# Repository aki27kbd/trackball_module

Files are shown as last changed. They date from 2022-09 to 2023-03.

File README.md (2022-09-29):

# trackball_module

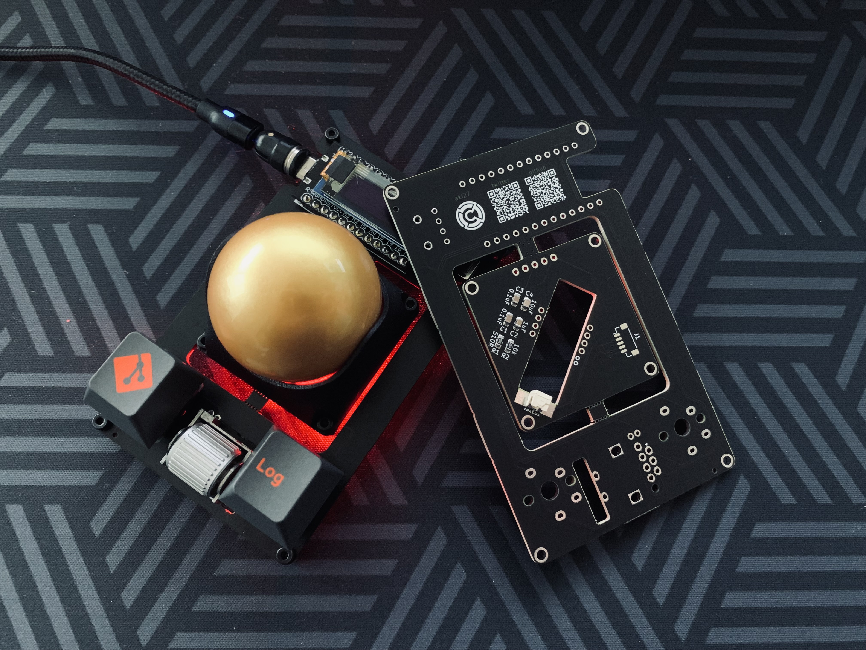
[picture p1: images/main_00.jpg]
trackball_module_main00


This is a module part for 34mm trackball with ADNS-5050 sensor. Module size is within 2u x 2u (38mm x 38mm) so that it can be easily implemented with existing DIY keyboards. Connection with other boards is via 2.54mm-pitched 5 pins or 1.0mm-pitched SH connector. The module is embedded with a Meishi (name card) sized PCB which can also work as a stand-alone mini trackball with two keys, a rotary encoder and an OLED display.

- Keyboard Maintainer: [aki27kbd](https://github.com/aki27kbd) [@aki27kbd](https://twitter.com/aki27kbd)
- Hardware Supported: meishi trackball module PCB, ProMicro
- Hardware Availability: [BOOTH](https://aki27.booth.pm)
  Go on sale in October 2022.

Build Guide [JP](doc/buildguide.md) / [EN](doc/buildguide_en.md)

## 1. Stand-alone Mini Trackball
Meishi trackball module can be used as a mini trackball running on QMK. Keycodes and rotary encoder settings are easily customized via [Remap](https://remap-keys.app/).

### BOM
|名前|数|備考|
|---|---|---|
|MicroUSB or USB-TypeCケーブル|1本||
|ProMicro|1個||
|コンスル― or ピンヘッダ（12ピン）|2本||
|キースイッチ|2個|MX互換 or Choc v1|
|キーキャップ（1U）|2個|MX互換 or Choc v1|
|ロータリーエンコーダ（EC12互換）|1個|水平タイプも可|
|ロータリーエンコーダ用ノブ|1個|最大直径16mm以下|
|OLEDモジュール|1個||
|OLED用ピンソケット|1個||
|OLED用ピンヘッダ|1個||
|リセットスイッチ|1個||
|34mmボール|1個||
|M2ねじ 6mm|4本||
|M2ナット|4個||
|アクリルボトムプレート|1枚|オプション|
|M2ねじ 4mm|8本||
|M2スペーサー 6mm|4本||

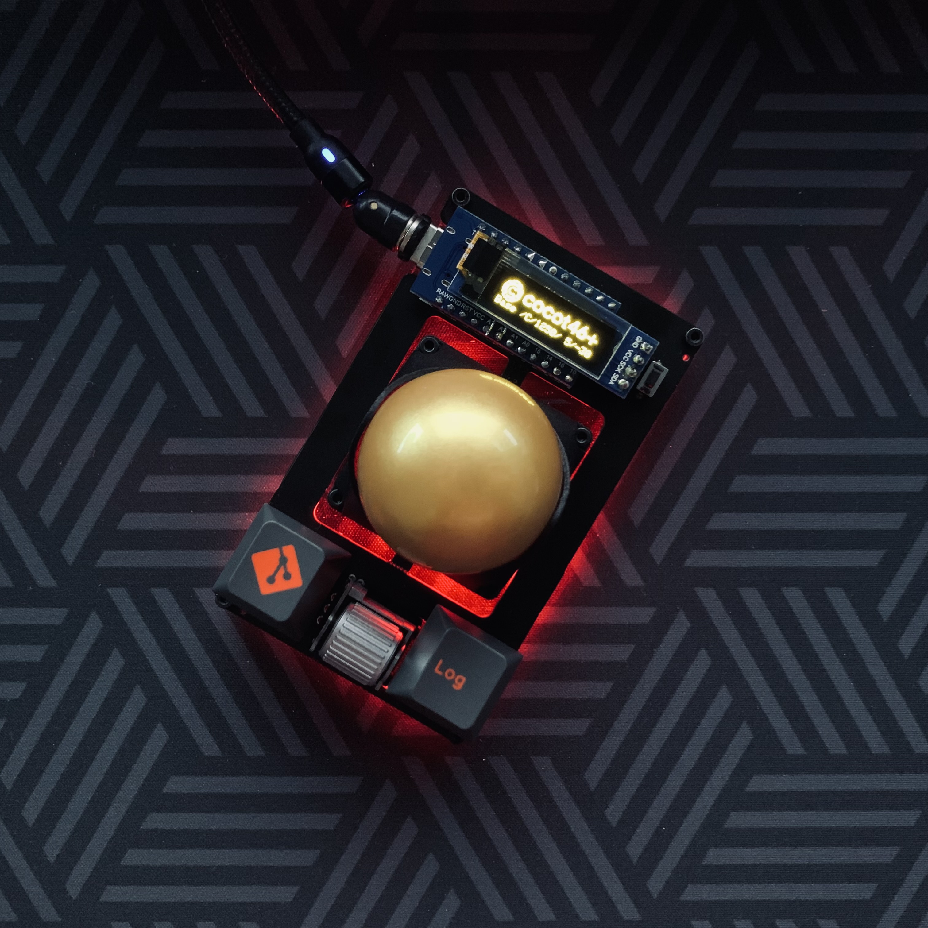
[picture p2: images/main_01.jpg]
trackball_module_main01


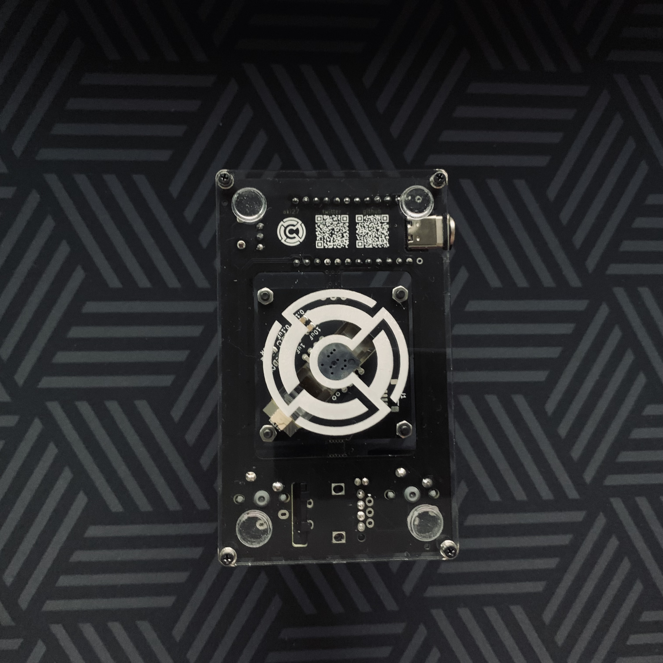
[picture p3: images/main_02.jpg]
trackball_module_main02


## 2. Trackball Module

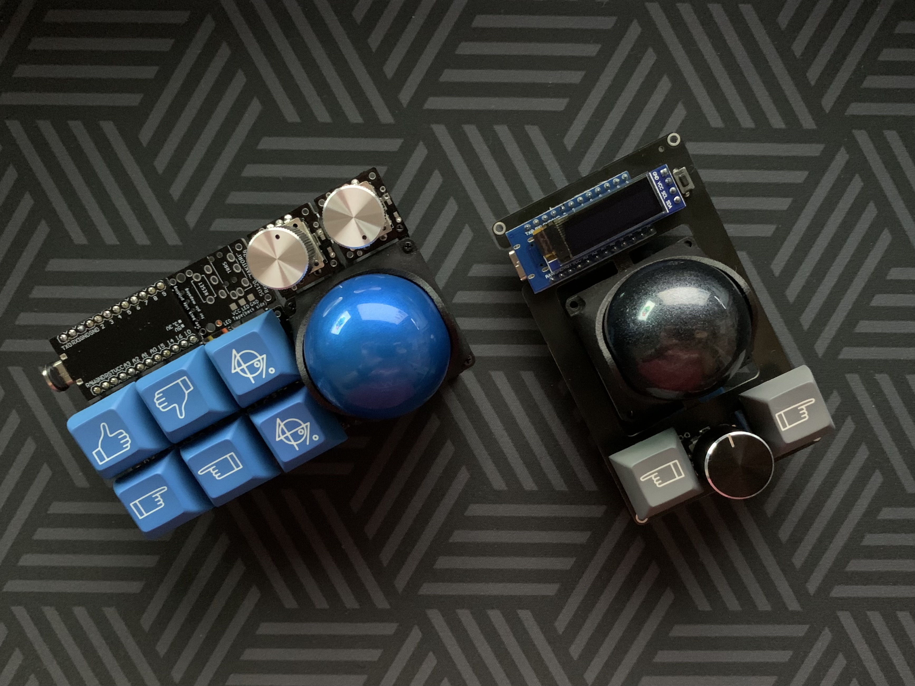
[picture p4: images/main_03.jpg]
trackball_module_main03


Square part located at the center of Meishi PCB can be cut off and used as a trackball module. There are several ways to connect this module with main boards.

1. Pin Headers & Pin Sockets  
  5 pins need to be connected. Straight and L-angle types are available.

2. Cables
  Cabling/wiring between pins of the module and the main board.

3. SH Connectors
  SH horizontal connectors are also supported for the connection with external boards.

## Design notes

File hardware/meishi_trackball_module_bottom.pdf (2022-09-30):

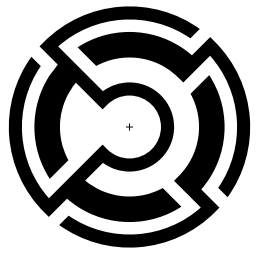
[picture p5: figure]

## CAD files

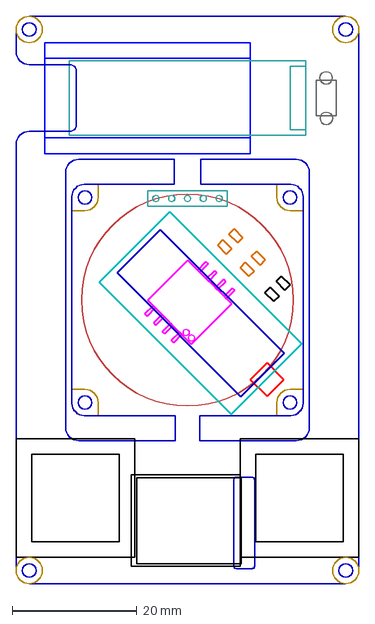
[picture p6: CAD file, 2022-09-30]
hardware/meishi_trackball_module_issue.dxf
55.0 x 91.0 mm

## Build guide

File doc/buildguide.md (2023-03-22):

# Build Guide

trackball_module_main00

trackball_module_main00

meishi trackball moduleのビルドガイドになります。
meishi trackball moduleは、名刺サイズ（55mm×91mm）の自作トラックボール検証基板です。そのまま組み立てることで、34mmトラックボールとスイッチ×2、ロータリーエンコーダ、OLEDを搭載したマウスやマクロパッドとして利用することが可能です。  
また、中央の2u×2u（38mm×38mm）のプレートは切り離すことで、そのままトラックボールモジュールとして他のキーボードに搭載可能です。詳細はこちらを参照ください。

## 部品
### キット付属品

#### ベースセット付属品

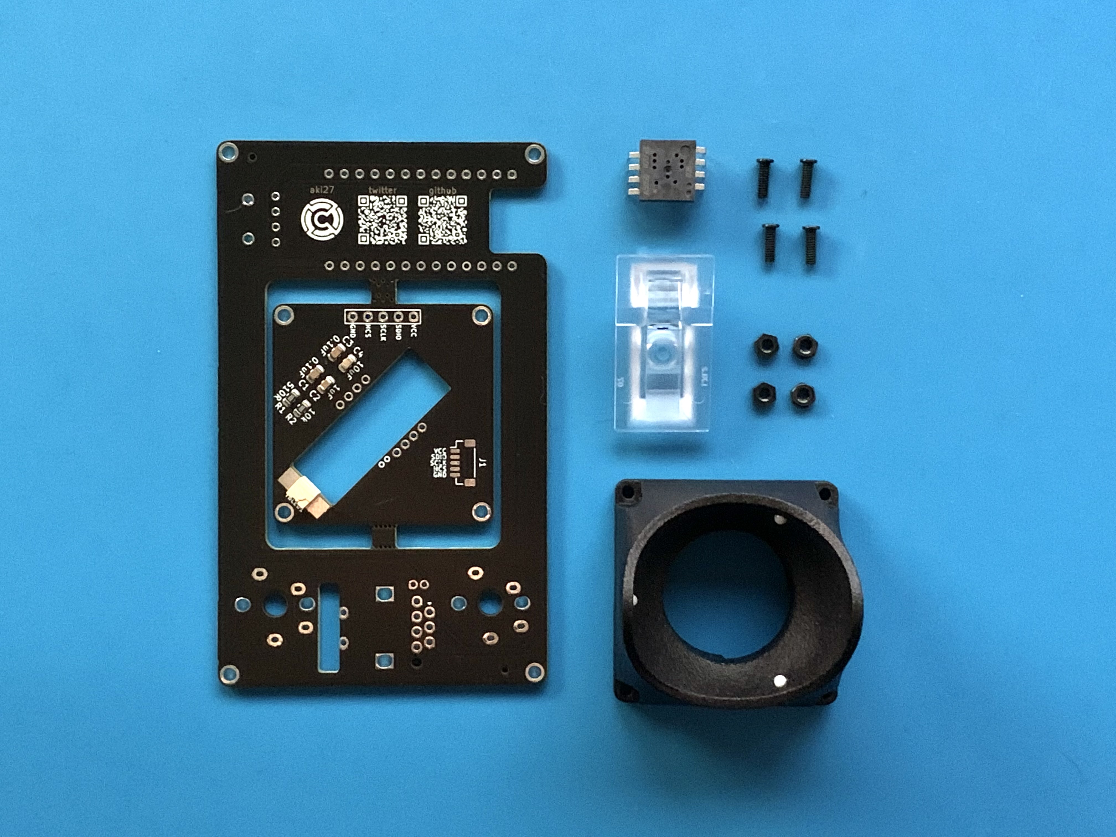
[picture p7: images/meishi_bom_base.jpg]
meishi_bom_bottom


#### アクリルボトムプレート付属品（オプション）

アクリルボトムプレートを自身で発注する際はこちらのデータを改編してお使いください。  
[アクリルボトムプレート](https://github.com/aki27kbd/trackball_module/blob/main/hardware/meishi_trackball_module_bottom.pdf)

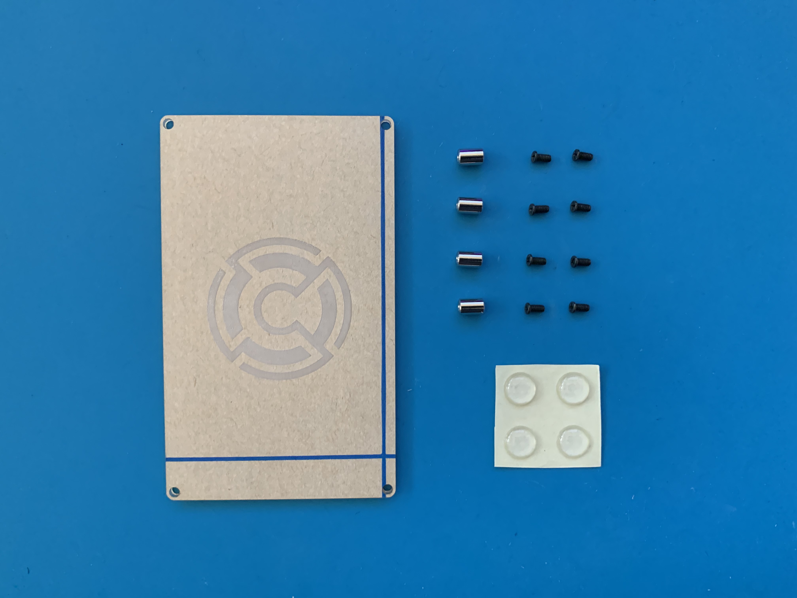
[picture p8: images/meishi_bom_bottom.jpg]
meishi_bom_bottom


|名前|数|備考|
|---|---|---|
|実装済基板|1枚||
|ProMicro|1個||
|マウスセンサー（ADNS-5050）|1個||
|センサーレンズ|1個||
|3Dプリント製ボールケース|1個||
|M2ねじ 6mm|4本||
|M2ナット|4個||
|アクリルボトムプレート|1枚|オプション|
|M2ねじ 4mm|8本|オプション|
|M2スペーサー 6mm|4本|オプション|
|ゴム脚|4個|オプション|

### キット以外に必要なもの

下記パーツは[遊舎工房](https://shop.yushakobo.jp/)、[TALP KEYBOARD](https://talpkeyboard.net/)、[Daily Craft Keyboard](https://shop.dailycraft.jp/)などで揃えることが可能です。また、18mm径ノブは[へちょあまの工房＠たねやつ支店](https://taneyats.booth.pm/items/3512697)での品揃えが豊富です。

|名前|数|備考|
|---|---|---|
|MicroUSB or USB-TypeCケーブル|1本||
|ProMicro|1個||
|コンスル― or ピンヘッダ（2.5mm×12ピン）|2本||
|キースイッチ|2個|MX互換 or Choc v1|
|キーキャップ（1U）|2個|MX互換 or Choc v1|
|ロータリーエンコーダ（EC12互換）|1個|水平タイプも可|
|ロータリーエンコーダ用ノブ|1個|最大直径18mm以下|
|OLEDモジュール|1個||
|OLED用ピンソケット|1個||
|OLED用ピンヘッダ|1個||
|リセットスイッチ|1個||
|34mmボール|1個||

各ショップの在庫状況に応じて検討ください。

## 組み立て

### 1. センサー

  基板の裏面からセンサーを固定します。写真の赤枠のように、センサーの丸印と基板の丸印の位置が揃うように気を付けてください。マスキングテープなどで固定した後、表側から8本の脚をはんだ付けしてください。

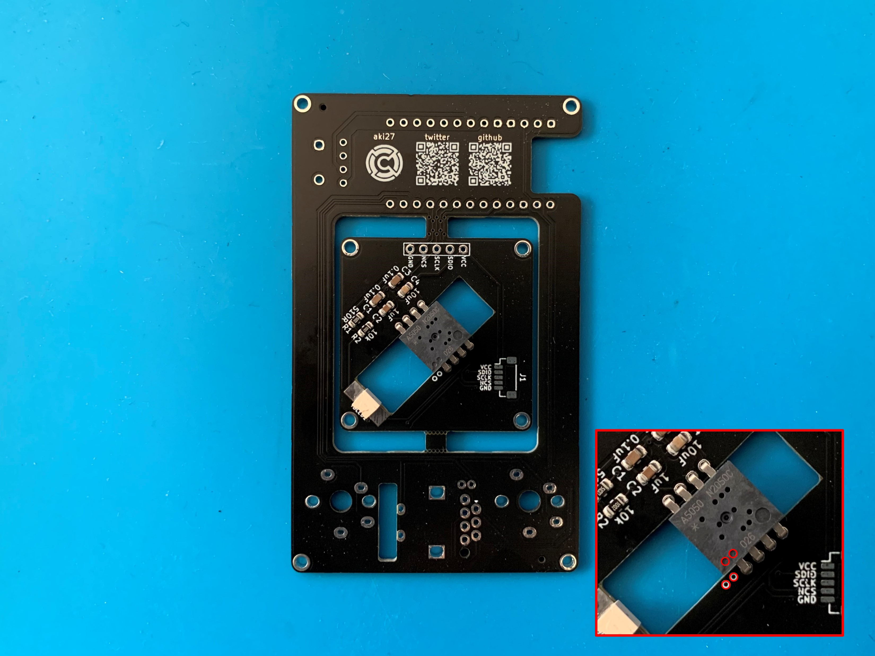
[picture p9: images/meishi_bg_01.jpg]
meishi_bg_01
  

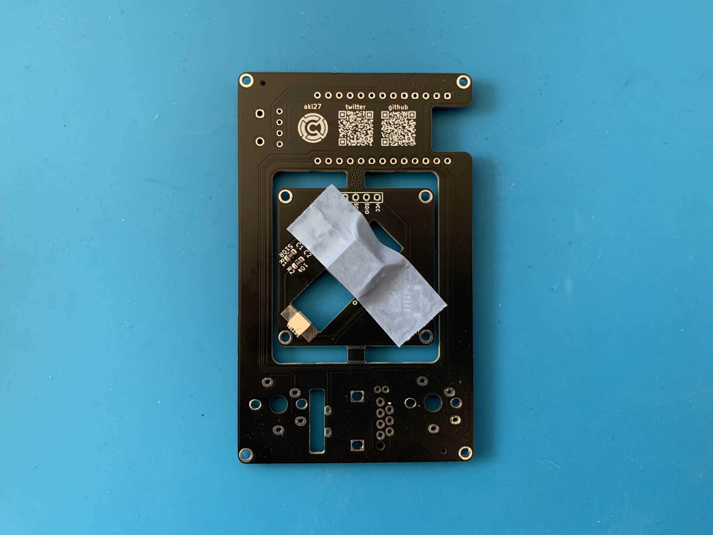
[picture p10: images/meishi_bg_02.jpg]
meishi_bg_02
  

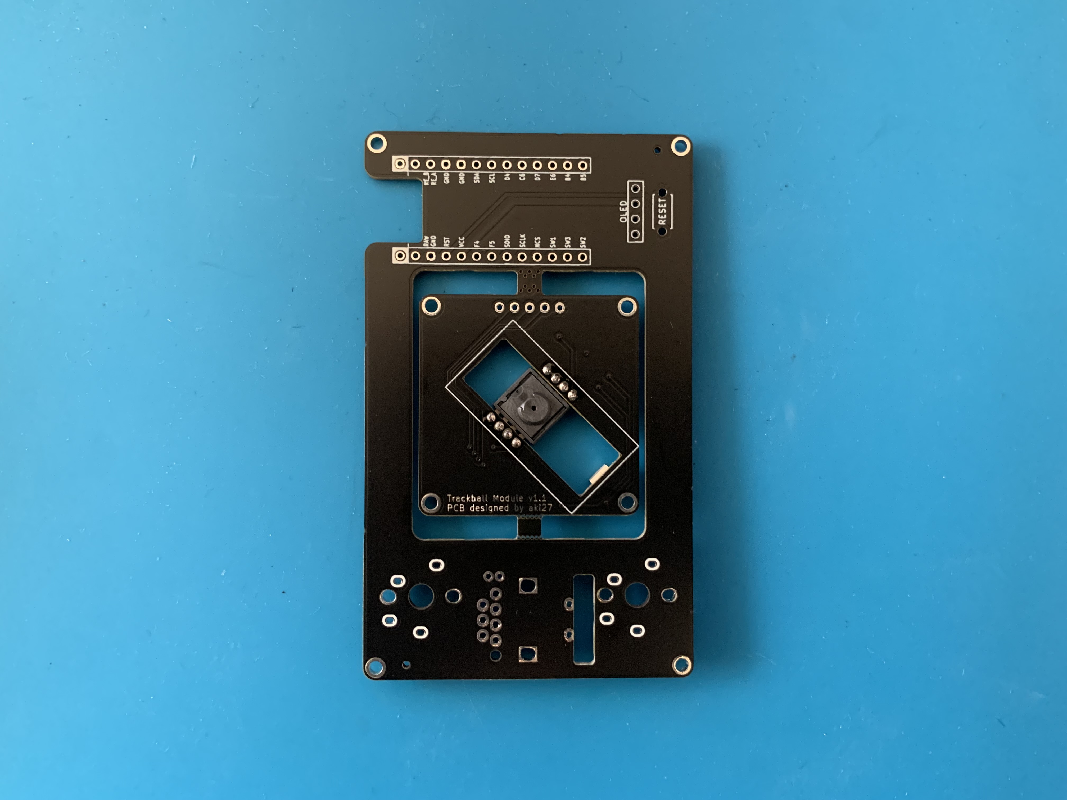
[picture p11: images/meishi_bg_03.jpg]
meishi_bg_03
  

### 2. ロータリーエンコーダ

  続いてロータリーエンコーダのはんだ付けを行います。**必ずキースイッチの前にロータリーエンコーダのはんだ付けを行ってください。**  
  水平ロータリーエンコーダの場合は下記写真のように表側から基板に固定し、裏側6本の脚をはんだ付けしてください。

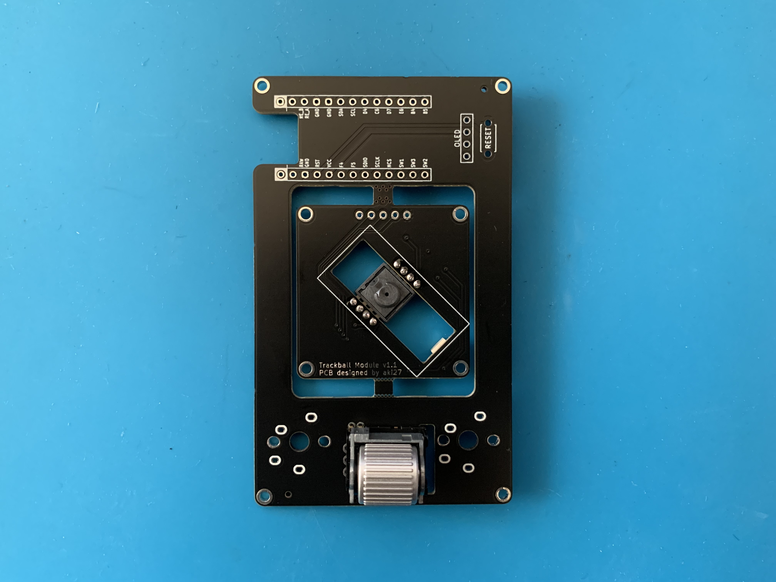
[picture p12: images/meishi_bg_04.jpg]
meishi_bg_04
  

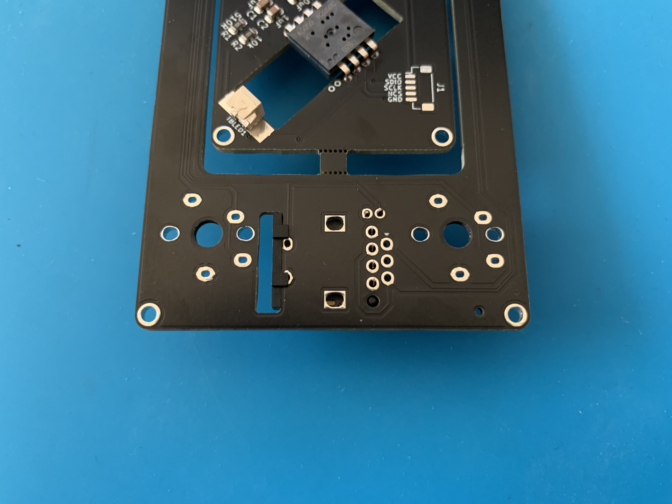
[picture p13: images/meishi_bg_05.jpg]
meishi_bg_05
  

  通常のロータリーエンコーダの場合は下記写真のように表側から基板に固定し、裏側5本の脚をはんだ付けしてください。

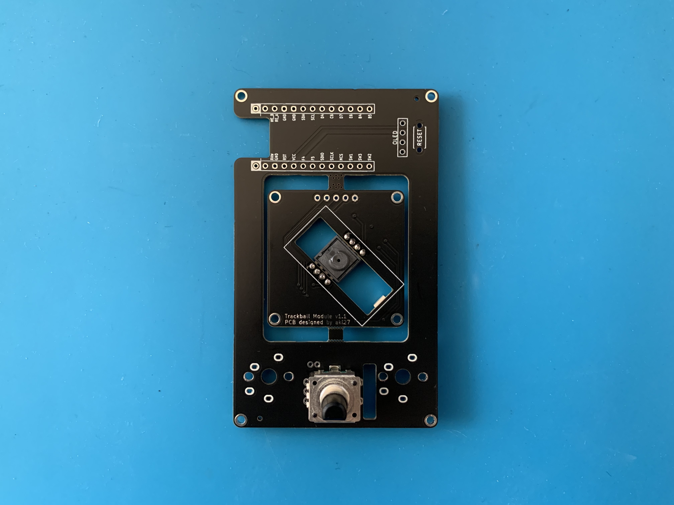
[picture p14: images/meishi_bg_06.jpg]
meishi_bg_06
  

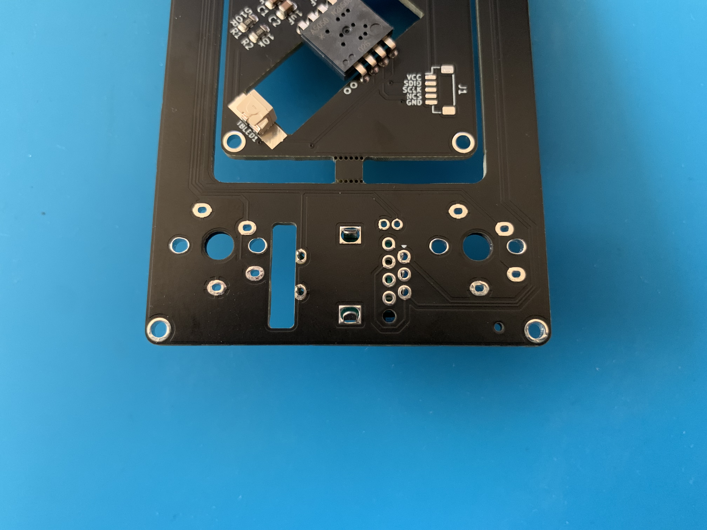
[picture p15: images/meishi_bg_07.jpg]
meishi_bg_07
  

### 3. キースイッチ

  キースイッチ2個を基板の表側から差し込み、裏側2本の脚×2個の計4か所のはんだ付けしてください。

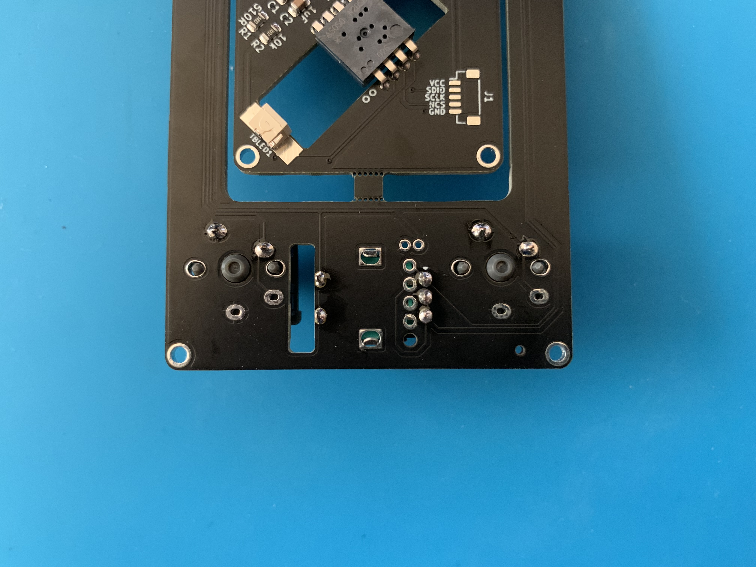
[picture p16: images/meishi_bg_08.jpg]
meishi_bg_08
  

### 4. その他パーツ（オプション）

  OLED用ピンソケットを基板表側から差し込み、マスキングテープなどで固定した後、裏側から4本の脚をはんだ付けしてください。

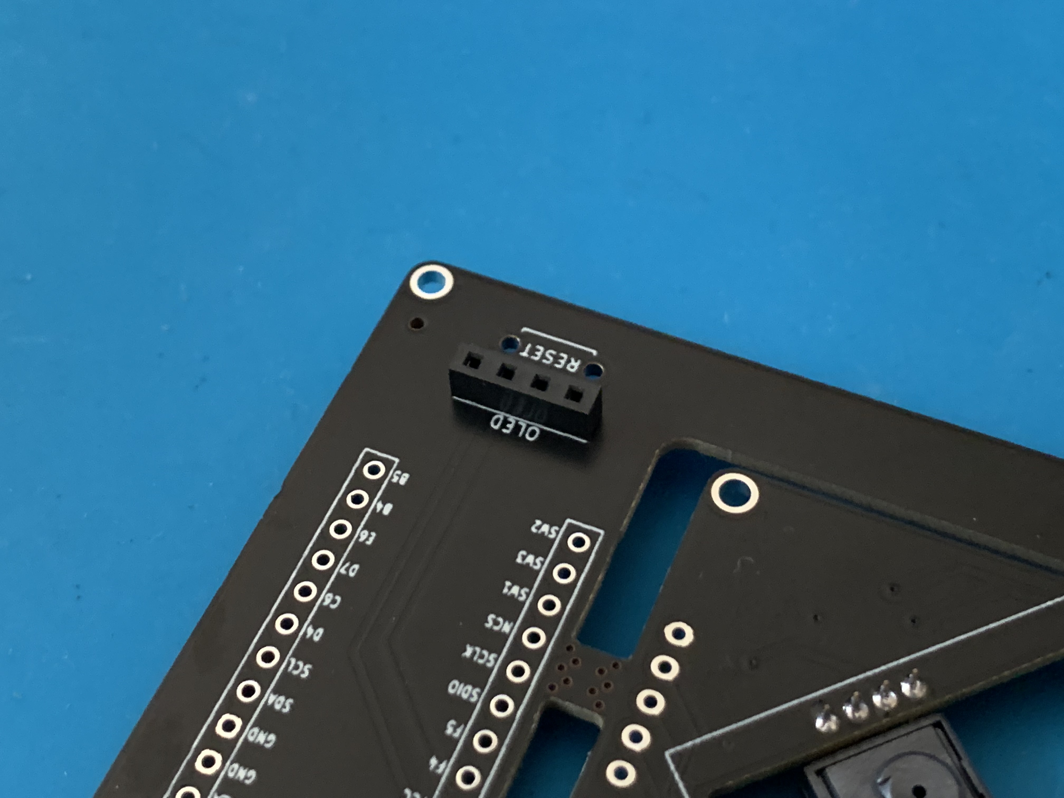
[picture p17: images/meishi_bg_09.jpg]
meishi_bg_09
  

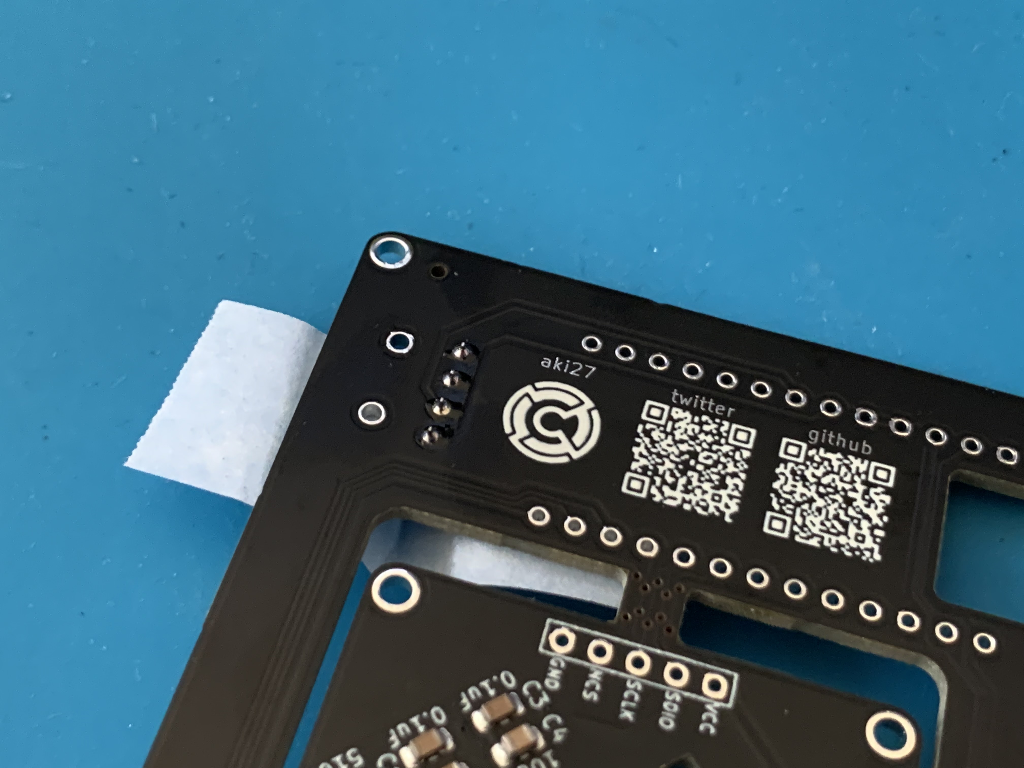
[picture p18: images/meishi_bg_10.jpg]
meishi_bg_10
  

  同様に、リセットスイッチも基板表側から差し込み、裏側から2本の脚をはんだ付けしてください。

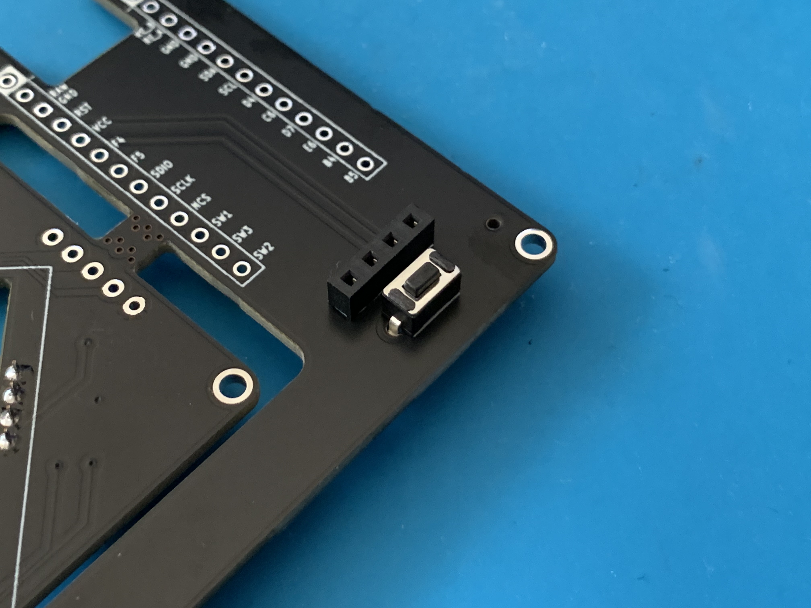
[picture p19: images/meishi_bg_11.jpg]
meishi_bg_11
  

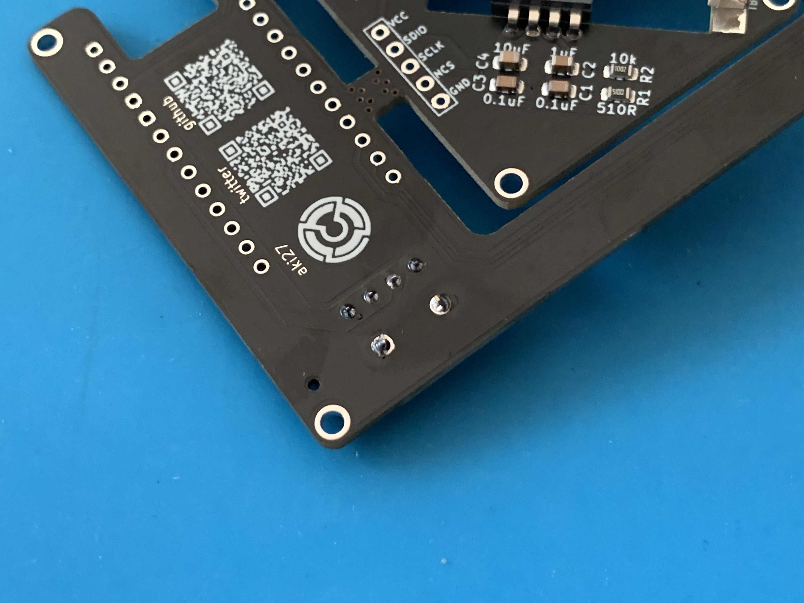
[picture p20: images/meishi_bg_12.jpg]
meishi_bg_12
  

  OLED用ピンヘッダをOLEDモジュールに差し込みます。ピンヘッダが斜めにならないよう気を付けながらはんだ付けをおこなってください。

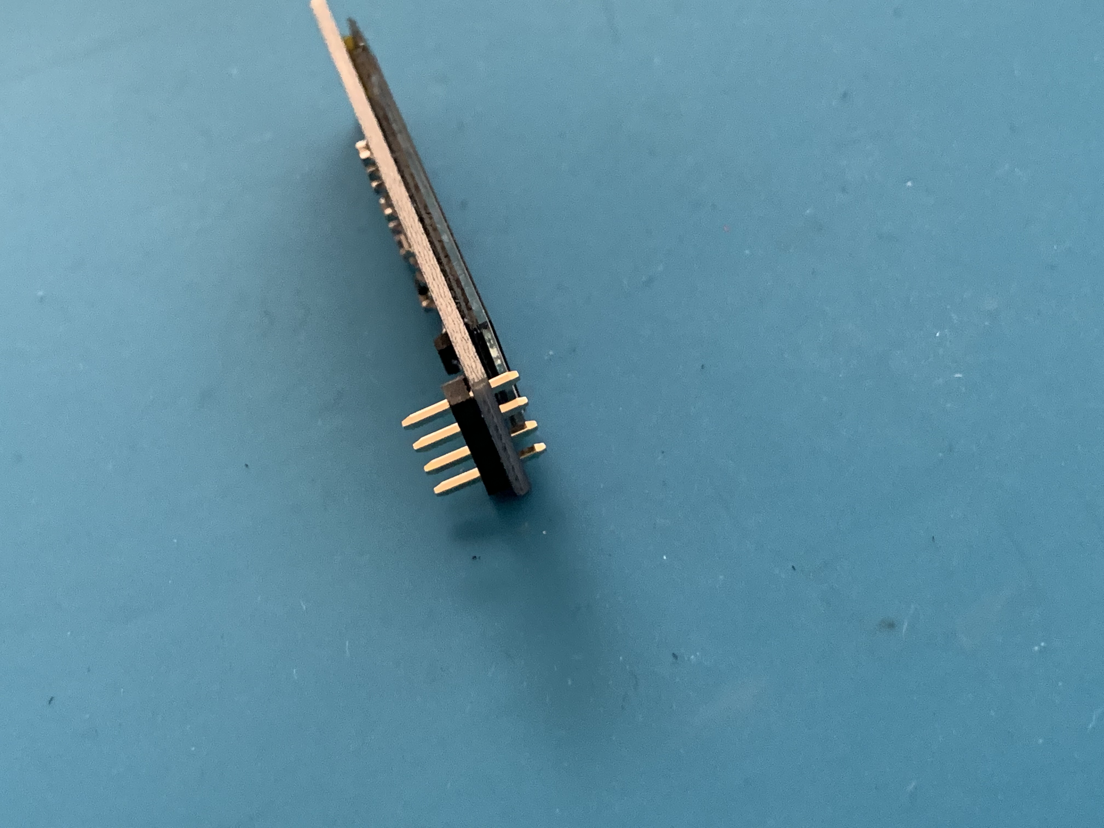
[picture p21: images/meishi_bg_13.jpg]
meishi_bg_13
  

  はんだ付けの行程は以上になります。

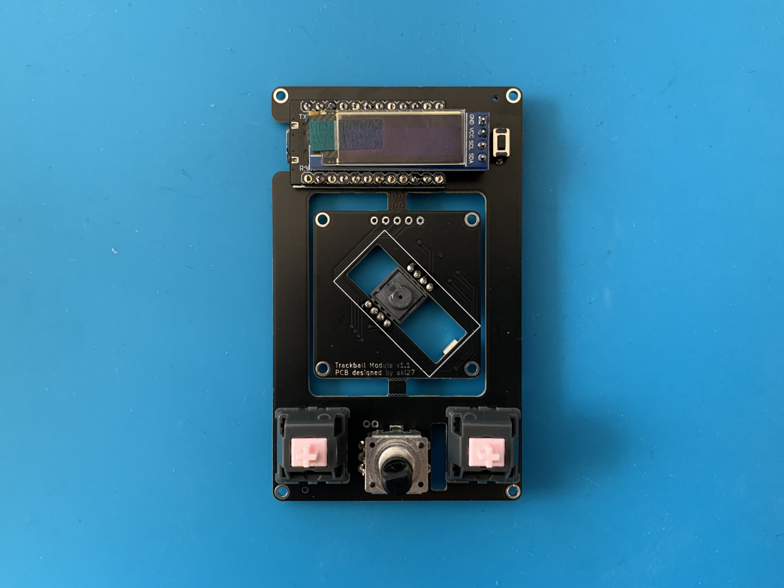
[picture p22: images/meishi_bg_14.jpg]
meishi_bg_14
  

### 5. ボールケース

ボールケースにセラミックボールを固定します。（写真はcocot46plusのボールケースになりますが、手順は同様です。）キット内容物以外に必要な道具は下記写真の通り、エポキシ2液混合接着剤、接着剤を取り出す容器、爪楊枝になります。  
cocot46plus_bg_ballcase_01

接着剤の取り扱い説明に沿って接着液の準備を行います。  
cocot46plus_bg_ballcase_02

爪楊枝の先端に接着剤を少量付け、ボールケース内側の穴に塗ります。塗りすぎるとボールを嵌めた際にあふれてしまうので、窪みの内側が接着剤で薄く覆われる程度を目安としてください。  
cocot46plus_bg_ballcase_03

cocot46plus_bg_ballcase_04

接着剤が乾く前にボールをはめ込みます。接着剤がボールの周りにあふれてしまった場合は固まる前にきれいにふき取ってください。  
cocot46plus_bg_ballcase_05

3箇所すべてボールを接着すればボールケースの準備完了です。  
cocot46plus_bg_ballcase_06

### 6. 組み立て

  センサー用レンズをセンサーの上に被せます。レンズの向きに注意してください。

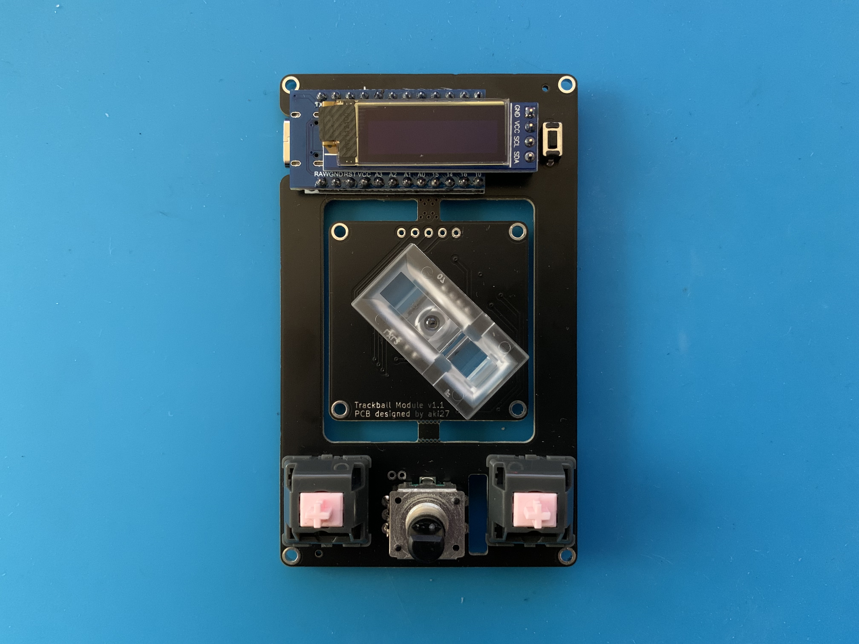
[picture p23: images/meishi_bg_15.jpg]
meishi_bg_15
  

  ボールケースをレンズ上から被せます。ボールケースの溝とレンズがぴったりはまるように向きに注意してください。

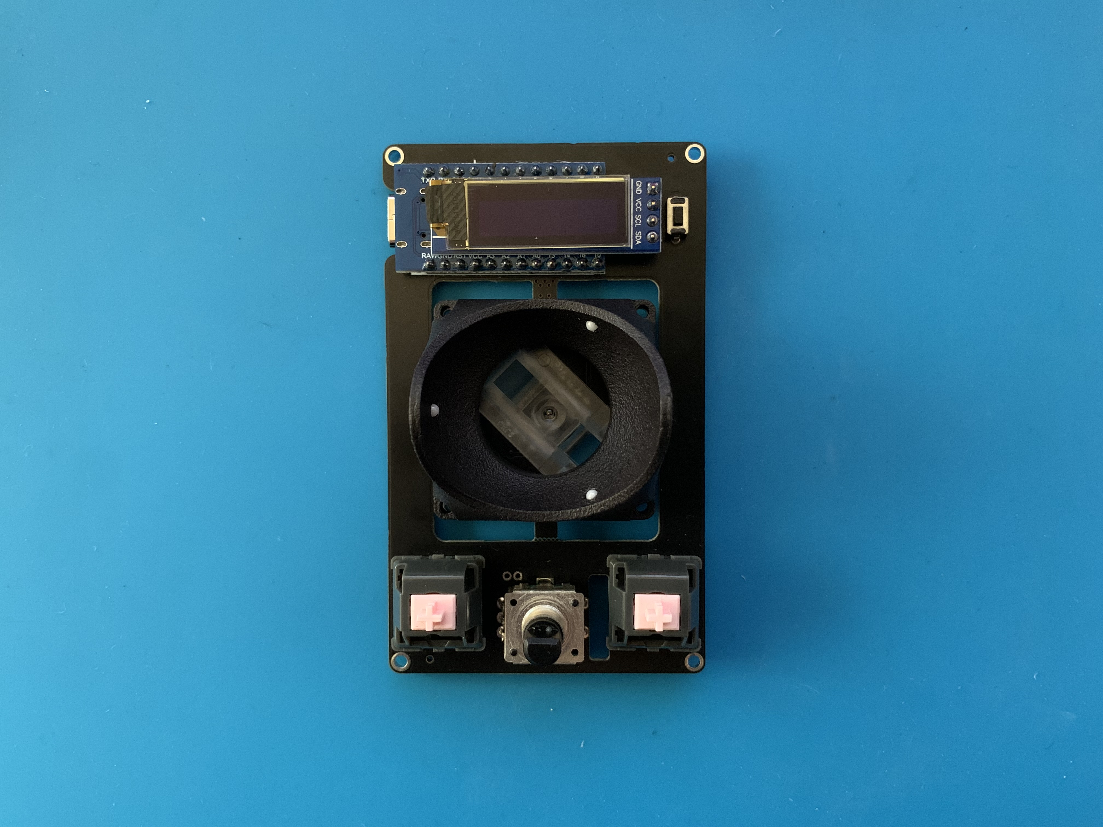
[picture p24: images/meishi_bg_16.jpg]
meishi_bg_16
  

  M2 6mmねじとナットでボールケースを基板に固定します。写真のように上からM2ねじを差し、裏側からナットで固定します。

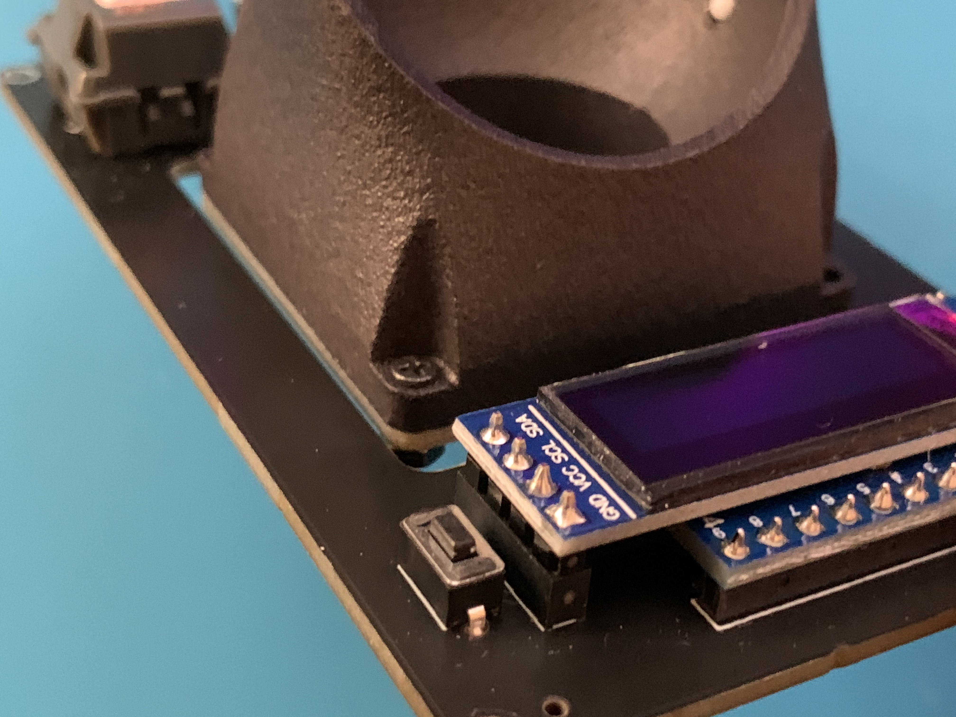
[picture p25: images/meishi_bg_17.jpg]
meishi_bg_17
  

  オプションのアクリルボトムプレートを組み立てる場合、まずアクリルプレートにM2 6mmスペーサーをM2ねじ4mmで固定します。

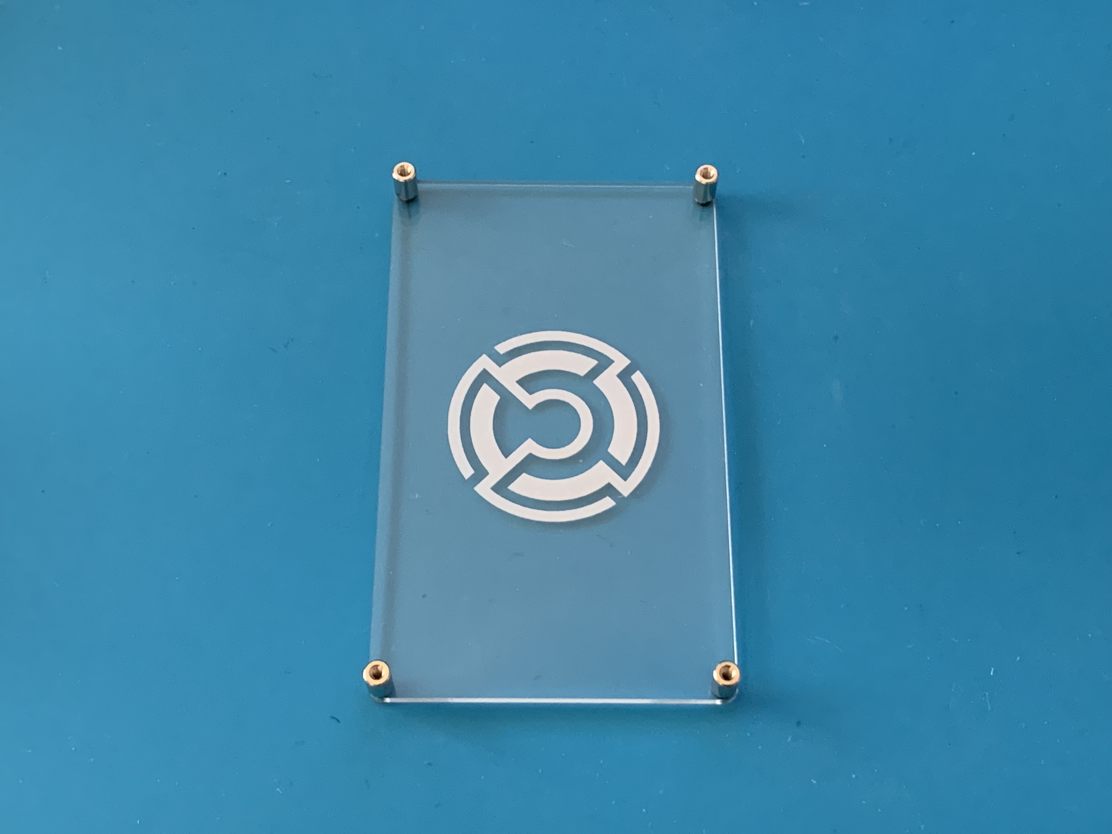
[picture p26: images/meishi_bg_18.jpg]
meishi_bg_18
  

  スペーサーの上に基板を重ね、基板上からもM2 4mmねじで固定します。

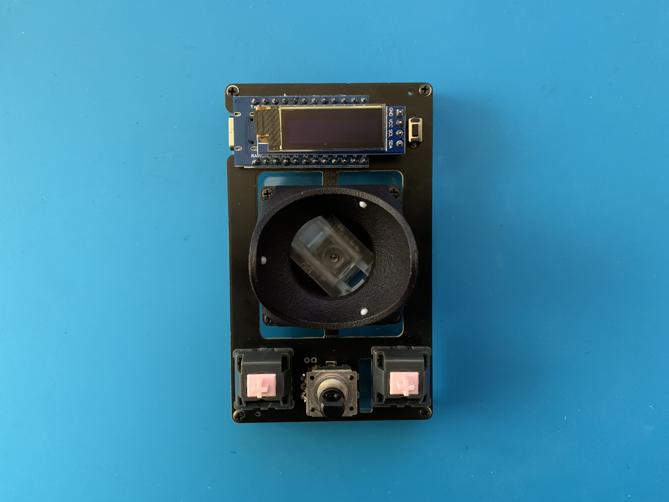
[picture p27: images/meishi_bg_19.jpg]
meishi_bg_19
  

  裏面にゴム脚を貼ります。

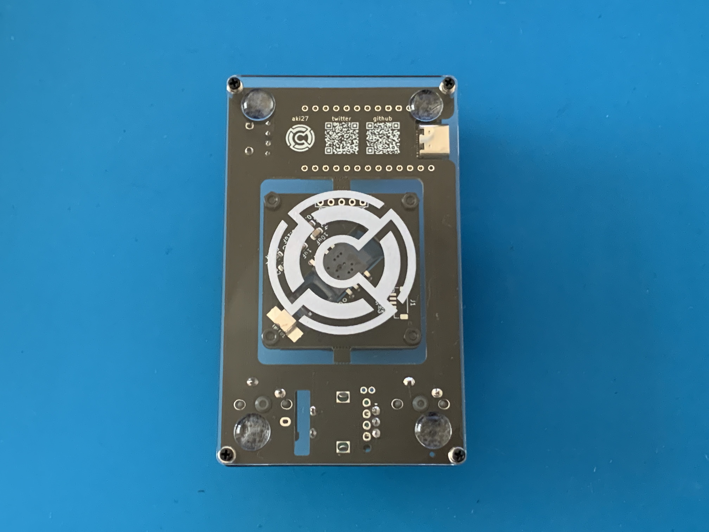
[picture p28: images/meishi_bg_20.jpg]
meishi_bg_20
  

  34mmボール、キーキャップ、ノブを付けて完成です！

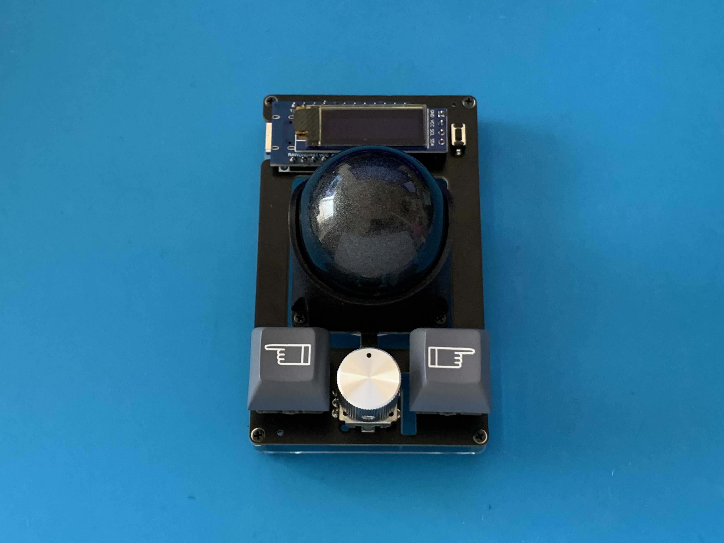
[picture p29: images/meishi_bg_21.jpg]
meishi_bg_21
  

## ファームウェア

  [REMAP](https://remap-keys.app/catalog/YTktEniNbS090Dnwr0mk/firmware)からファームウェアのダウンロードおよびProMicroへの書き込みを行うことができます。キーマップは[こちら](https://remap-keys.app/configure)から更新可能です。  
トラックボール、LED含めて上記.hexファイルで確認いただけます。

（.hexファイルをQMK ToolboxなどでProMicroに書き込む従来の方法でも問題ありません。）

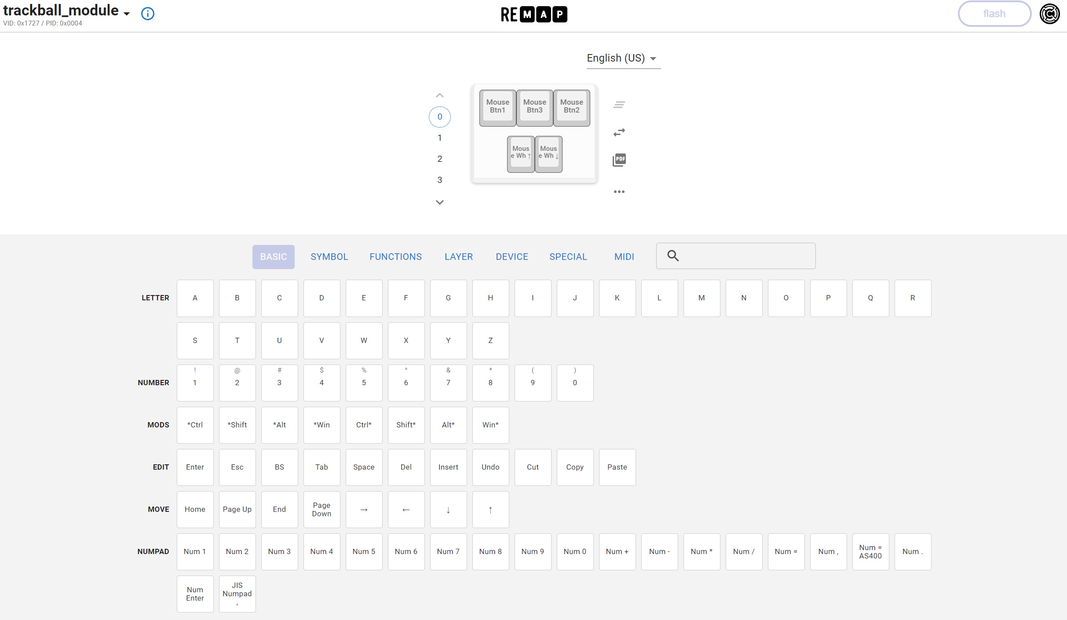
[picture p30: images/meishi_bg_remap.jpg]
REMAP


組み立て段階で動作確認をする際も、REMAPのTest Matrix Modeを使うと便利です。ただし、Test Matrix Modeではロータリーエンコーダの回転は確認できないので、別途キー入力等で動作を試してください。

ソースコードは[こちら](https://github.com/aki27kbd/qmk_firmware/tree/master/keyboards/aki27/trackball_module)を参照ください。  
また、VIA用のjsonファイルは[こちら](https://github.com/aki27kbd/trackball_module/blob/main/firmware/trackball_module_via.json)を参照ください。

## OLED

  OLEDにはトラックボールの情報を表示することが可能です。

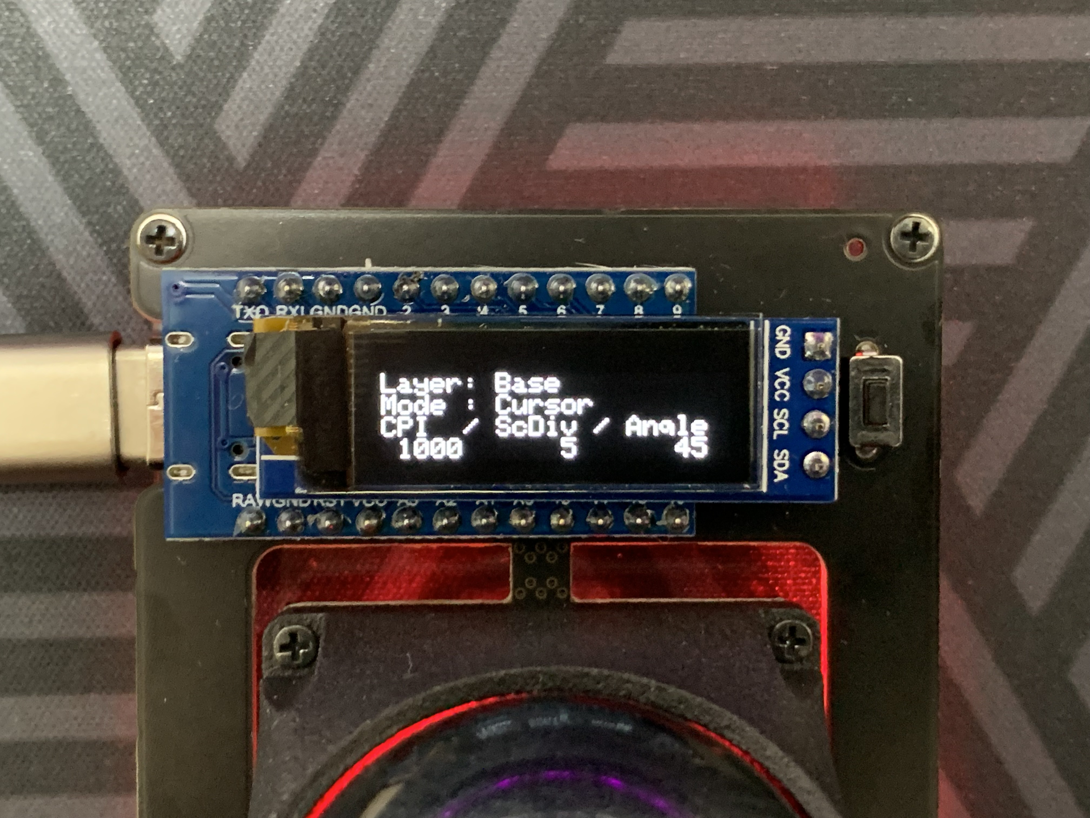
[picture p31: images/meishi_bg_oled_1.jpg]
meishi_bg_oled_1
  

  OLED|Description
  ---------|-----------
  Layer|現在のレイヤーを示します。
  Mode|Cursor:カーソル/Scroll:スクロールモードを示します。
  CPI|カーソルモードのCPIを示します。
  ScDiv|スクロールモードにおけるセンサーの感度を示します。数値が大きいほどスクロール量が小さくなります。
  Angle|マウスセンサーのY軸の回転角を示します。

  手の大きさやトラックボールへの手の置き方によって、操作しやすいY軸の回転角が異なります。`ROT_R15`、`ROT_L15`キーで調整しながら自分に合った設定を探してみてください。

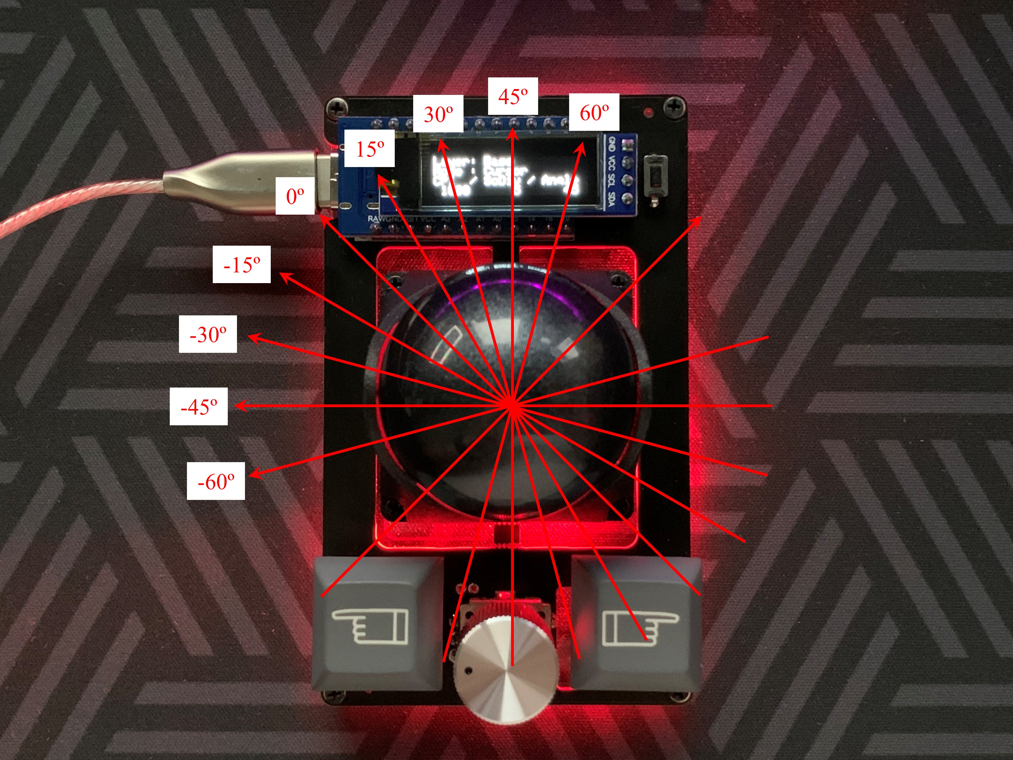
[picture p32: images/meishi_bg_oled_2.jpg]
meishi_bg_oled_2
  

## 終わりに
何かトラブルがあれば[Twitterアカウント](https://twitter.com/aki27kbd)までご連絡ください。

また、完成写真をSNSにアップいただけるととても励みになります。（アップするのがはばかられる方はDMで直接送りつけていただいても構いません。）

ハッシュタグは #trackball_module です。

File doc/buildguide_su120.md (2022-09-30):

# Build Guide - SU120 Customize

trackball_module_main00

meishi trackball moduleをモジュールとして他のキーボードに接続する作例を紹介します。
トラックボールモジュールをキーボードに接続する条件は下記になります。

- GPIOピンに3ピン以上空きがあること
- 5V電源のProMicro互換機であること（3.3V電源の機器を用いる場合はレベル変換が必要になります。）

ここでは様々なレイアウトのスタディを行う事に長けているSU120を用いて、トラックボール付きのマクロパッドを作成します。

## 部品

meishi trackball moduleのベースキットの他に、下記パーツを用います。ご自身のレイアウトに応じて適宜数字を読み替えてください。

|名前|数|備考|
|---|---|---|
|SU120基板|適宜||
|M1.4ねじ 5mm|適宜||
|M1.4ねじ 8mm|2～4本||
|M1.4ナット|適宜||
|MicroUSB or USB-TypeCケーブル|1本||
|ProMicro|1個||
|コンスル― or ピンヘッダ（2.5mm×12ピン）|2本||
|キースイッチ|適宜|MX互換 or Choc v1|
|キーキャップ|適宜|MX互換 or Choc v1|
|ロータリーエンコーダ（EC12互換）|0～4個||
|ロータリーエンコーダ用ノブ|0～4個||
|リセットスイッチ|1個||
|34mmボール|1個||

上記パーツは[遊舎工房](https://shop.yushakobo.jp/)、[TALP KEYBOARD](https://talpkeyboard.net/)、[Daily Craft Keyboard](https://shop.dailycraft.jp/)などで揃えることが可能です。また、18mm径ノブは[へちょあまの工房＠たねやつ支店](https://taneyats.booth.pm/items/3512697)での品揃えが豊富です。

各ショップの在庫状況に応じて検討ください。

## 組み立て
### 0. レイアウト検討

  まずはどんなレイアウトのマクロパッドを作成するか検討します。trackball moduleは2u×2uサイズで設計されているので、4キー分のスペースにちょうどおさまります。

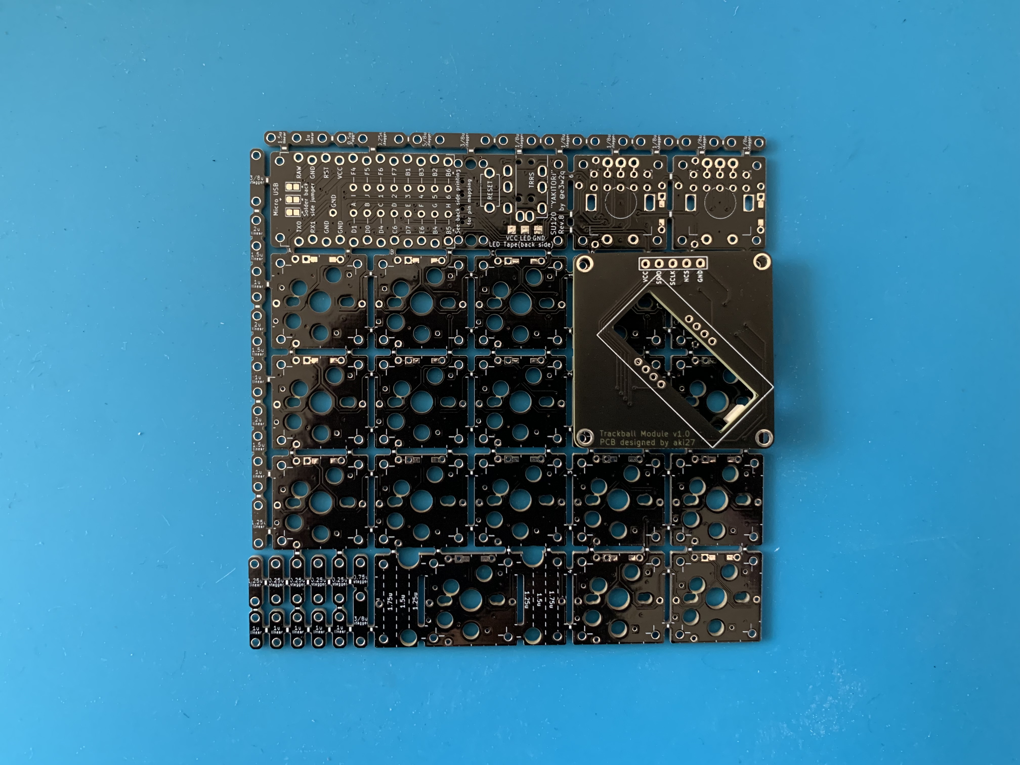
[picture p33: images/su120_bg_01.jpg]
su120_bg_01
  

  今回は2×3の6キー+ロータリーエンコーダ2個のレイアウトで進めます。SU120の基板を切り離し、やすりなどでバリを取っておきます。

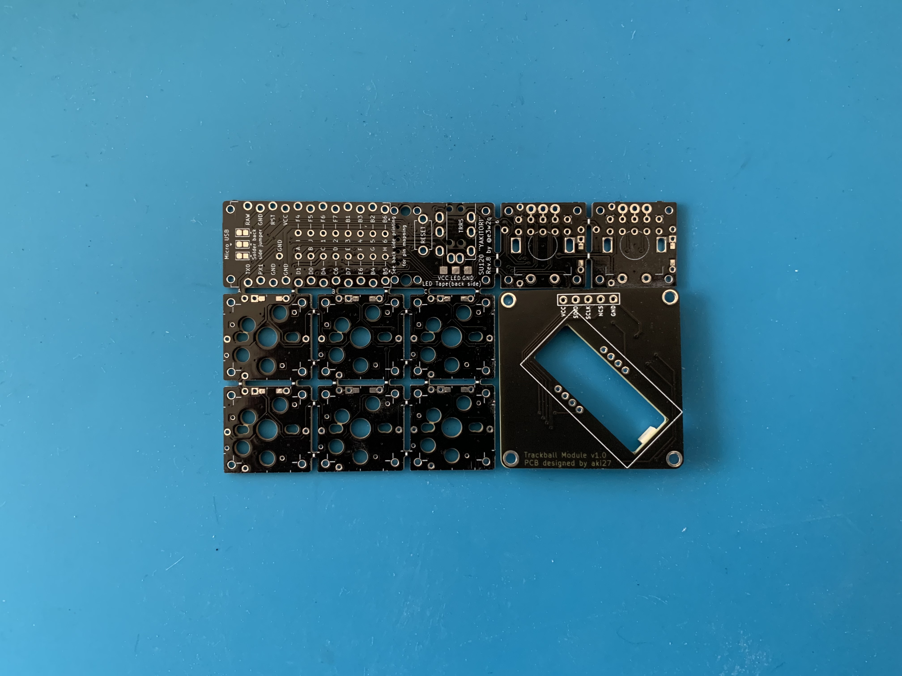
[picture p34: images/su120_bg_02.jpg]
su120_bg_02
  

### 1. パーツ類はんだ付け

  ソケット、ダイオード、ロータリーエンコーダ、ジャンパーなど必要箇所のはんだ付けを行います。SU120のビルドガイドや作例を参考にしてください。

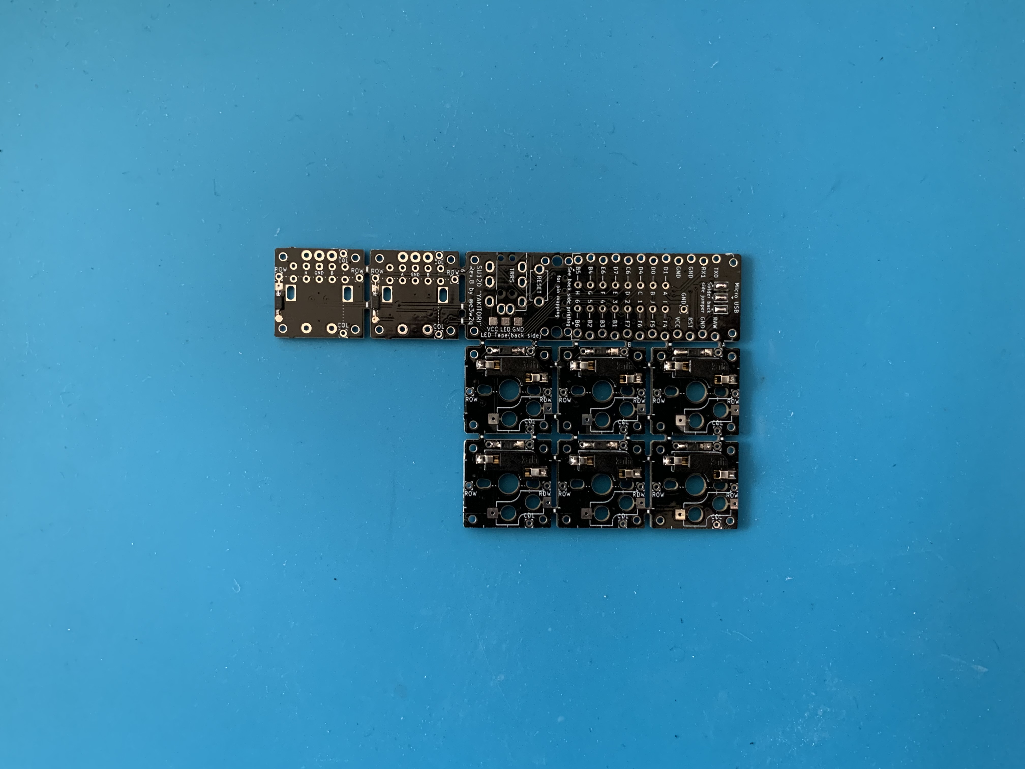
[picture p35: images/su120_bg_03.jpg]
su120_bg_03
  

### 2. 組み立て

  SU120の基板とトラックボールモジュールを固定します。SU120の基板に付属しているビスケットを用いて固定します。今回は格子配列のため1u Linearと書かれたビスケットを3つ用いています。

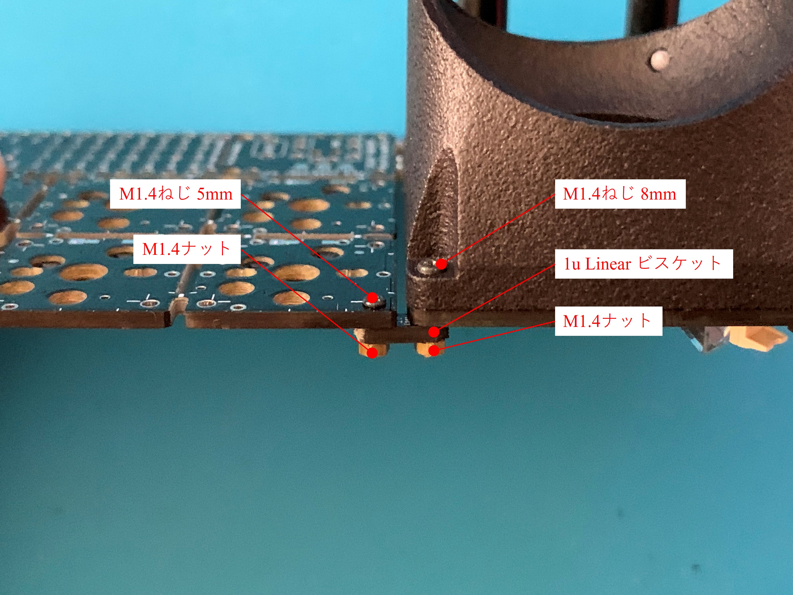
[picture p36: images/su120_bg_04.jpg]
su120_bg_04
  

  SU120の基板とトラックボールモジュールが接する部分はM1.4ねじ 8mm＋M1.4ナットでビスケットを固定します。SU120と接続しないトラックボールモジュールのねじ穴は通常通りM2ねじ 6mm＋M2ナットで固定します。  
  M1.4ねじ 8mmは[こちら](https://wilco.jp/products/F/F-EB-03.html#page1)がおすすめです。トラックボールホルダーのねじ穴がM2用に設計されているので、ねじ頭が2.5mm以上のものが望ましいです。

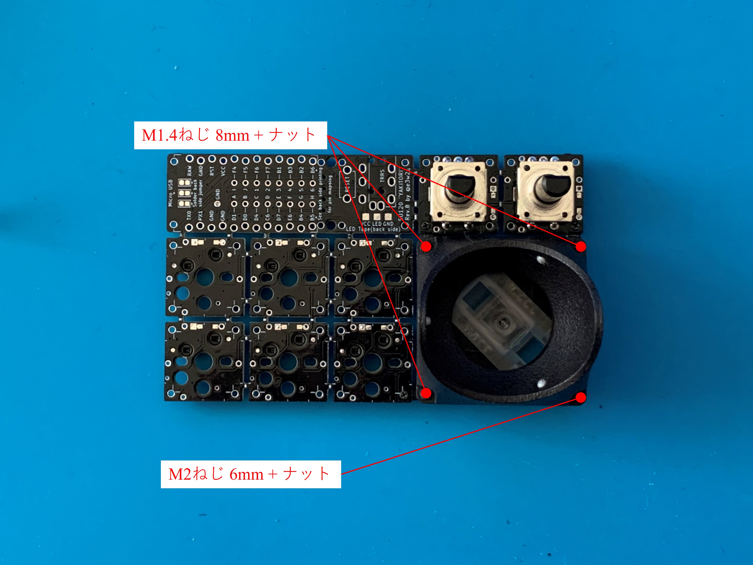
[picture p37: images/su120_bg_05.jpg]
su120_bg_05
  

### 3. センサー接続

  トラックボールモジュールのピンとSU120をケーブルで接続します。下記5本の接続が必要になります。

    - VCC
    - SDIO
    - SCLK
    - NCS
    - GND

  VCCとGNDはLED用のパッドかTRRSジャックのスルーホールにケーブルをはんだ付けするのが簡単です。

  それ以外の3ピンは、ファーム上で設定する空きピンに対応したピンに接続するようにしてください。空きピンとなる3ピンは、SU120の回路図を見ながら自分の選んだレイアウトに応じて選択してください。

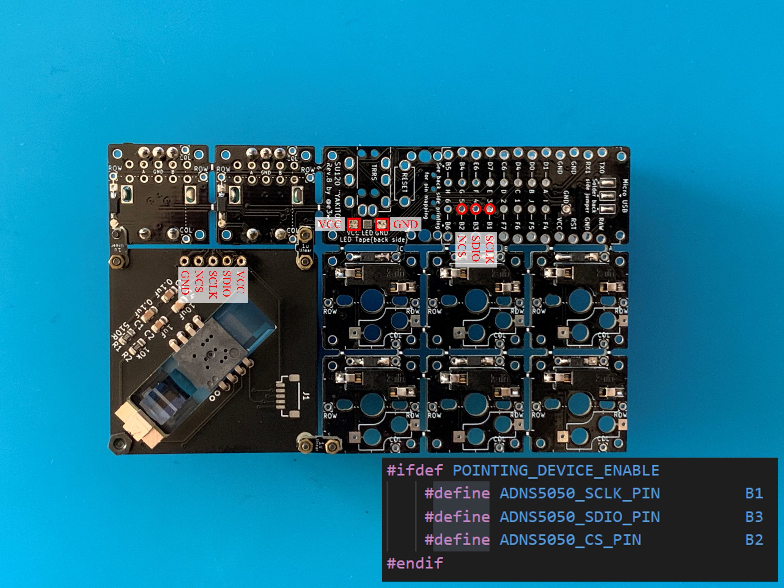
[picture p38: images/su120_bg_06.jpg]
su120_bg_06
  

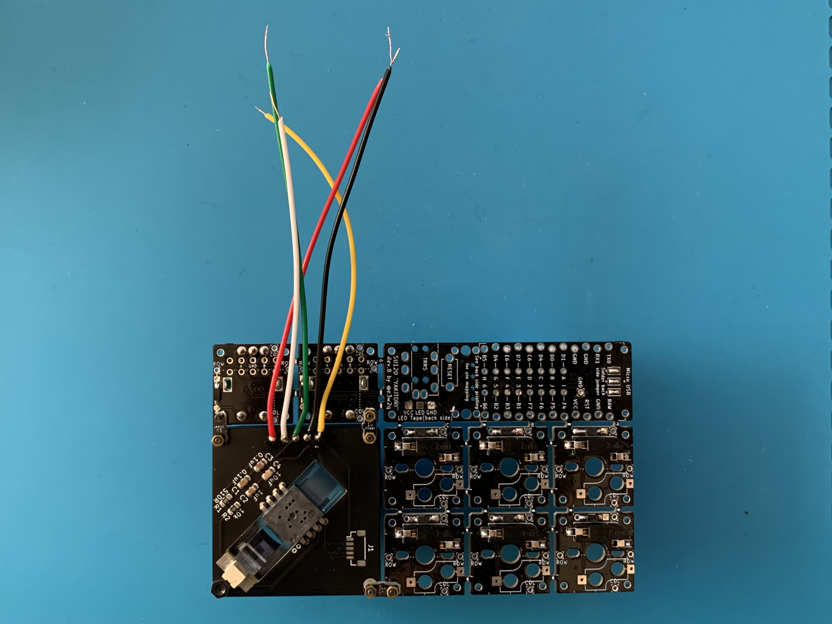
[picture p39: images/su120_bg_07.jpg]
su120_bg_07
  

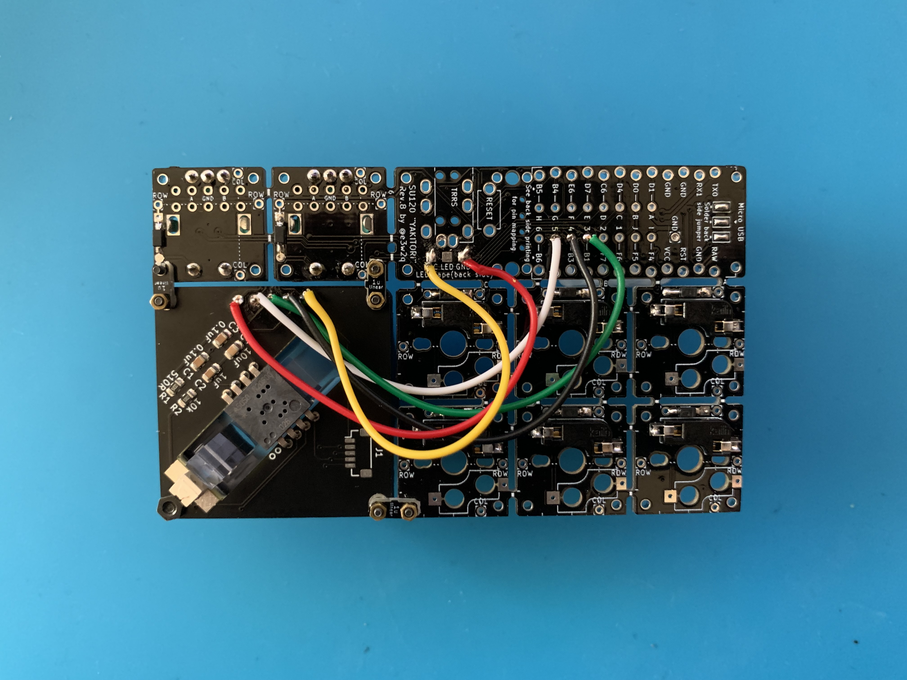
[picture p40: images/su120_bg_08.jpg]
su120_bg_08
  

  最後にキースイッチ、キーキャップ、ロータリーエンコーダ、トラックボールなどをはめて完成です。

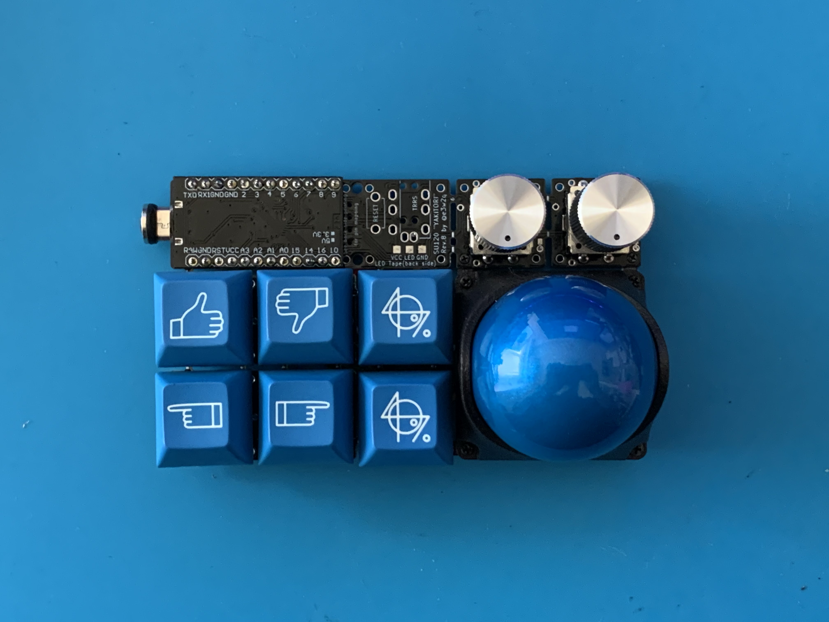
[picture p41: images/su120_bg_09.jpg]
su120_bg_09
  

## ファームウェア

  SU120のものをベースに書き換えます。[こちら]()を参考に、自身のレイアウトに合わせてファームウェアの更新を行い、ProMicroに書き込みを行ってください。

  meishi trackball moduleやcocot46plus同様にカスタムキーコードによってトラックボールの状態を変更することも可能です。

## Next Step

  SU120でのトラックボール実装ができたら、次はオリジナルのトラックボール搭載キーボードにチャレンジしてみてください。  
  meishi trackball moduleの外形線やパーツ配置、ねじ穴の位置などは[meishi_trackball_module_issue.dxf](https://github.com/aki27kbd/trackball_module/blob/main/hardware/meishi_trackball_module_issue.dxf)を参照してください。  
  また、基板上にセンサーなどを実装することにチャレンジする場合はこちらの[回路図](https://github.com/aki27kbd/trackball_module/blob/main/hardware/meishi_trackball_module_schematics.pdf)を参考にしてください。

  *部品の入手性などを考慮して、一部抵抗やコンデンサなどデータシートに記載された値から変えているものがありますのでご注意ください。  
  *データ改編やこちらのデータを元に自身で作成されたものに関しては一切の責任を負いません。あらかじめご了承ください。

## 終わりに

  何かトラブルがあれば[Twitterアカウント](https://twitter.com/aki27kbd)までご連絡ください。

  また、完成写真をSNSにアップいただけるととても励みになります。（アップするのがはばかられる方はDMで直接送りつけていただいても構いません。）

ハッシュタグは #trackball_module です。

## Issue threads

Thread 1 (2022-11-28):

M2 spacers

idank, 2022-11-28:
Hi, where do you buy the M2 spacers? Are they on aliexpress? Thanks!

protieusz, 2023-03-10:
I bought mine from here https://vi.aliexpress.com/item/32879956829.html?

idank, 2023-03-11:
Yeah but those are gold, it doesn't seem there are silver ones on
aliexpress.

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

PancakeGoon, 2023-03-11:
Just keep searching, there are spacers & standoffs of all shapes, sizes &
colors on Ali (don't know your region, I'm in the US). Just search for "M2
round standoff" (threaded) or spacer if you want it unthreaded.

    [TIP:] AliExpress uses a "Smart" Algorithm that tends to give weak &
repetitive results from promoted vendors until you start clicking through
the related 'Recommended Products' that are closer to your wants a bit.

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

PancakeGoon, 2023-03-11:
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

Here are some silver & round M2 threaded standoffs in an assortment of lengths (6mm, 8mm, 10mm, etc.):
https://a.aliexpress.com/_mM2uRKA
>
And here are some HEXAGONAL sets of standoffs in M2/M2.5/M3 and an assortment of colors & lengths:
https://a.aliexpress.com/_ms5tF0i
>
>
> I tend to hate M2 standoffs & screws as they're so small and lack sturdiness, as well as being generally harder to find in more unique shapes, styles & colors. I really wish KB designers would bump the "standard" up to at least 3mm/M3, and I know this isn't exactly a hot take. But I have found enough stuff to get by on Ali & other vendors for aesthetically-pleasing M2 spacers/standoffs & hardware to get by (custom FPV/Drone parts stores are a solid lead).

But yeah, if the abovelinks aren't good enough (was just the first relevant results I saw with a quick search), you can search through the recommended products and I'm sure you'll see some more results appear after CLICKING through some in your preference!

Closed 2023-03-22.

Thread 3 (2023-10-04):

Is this no longer maintained?

oilcrest, 2023-10-04:
Is this project no longer maintained or going to be in stock? If so, can the KiCad project files for this doesn't get left in the dust?

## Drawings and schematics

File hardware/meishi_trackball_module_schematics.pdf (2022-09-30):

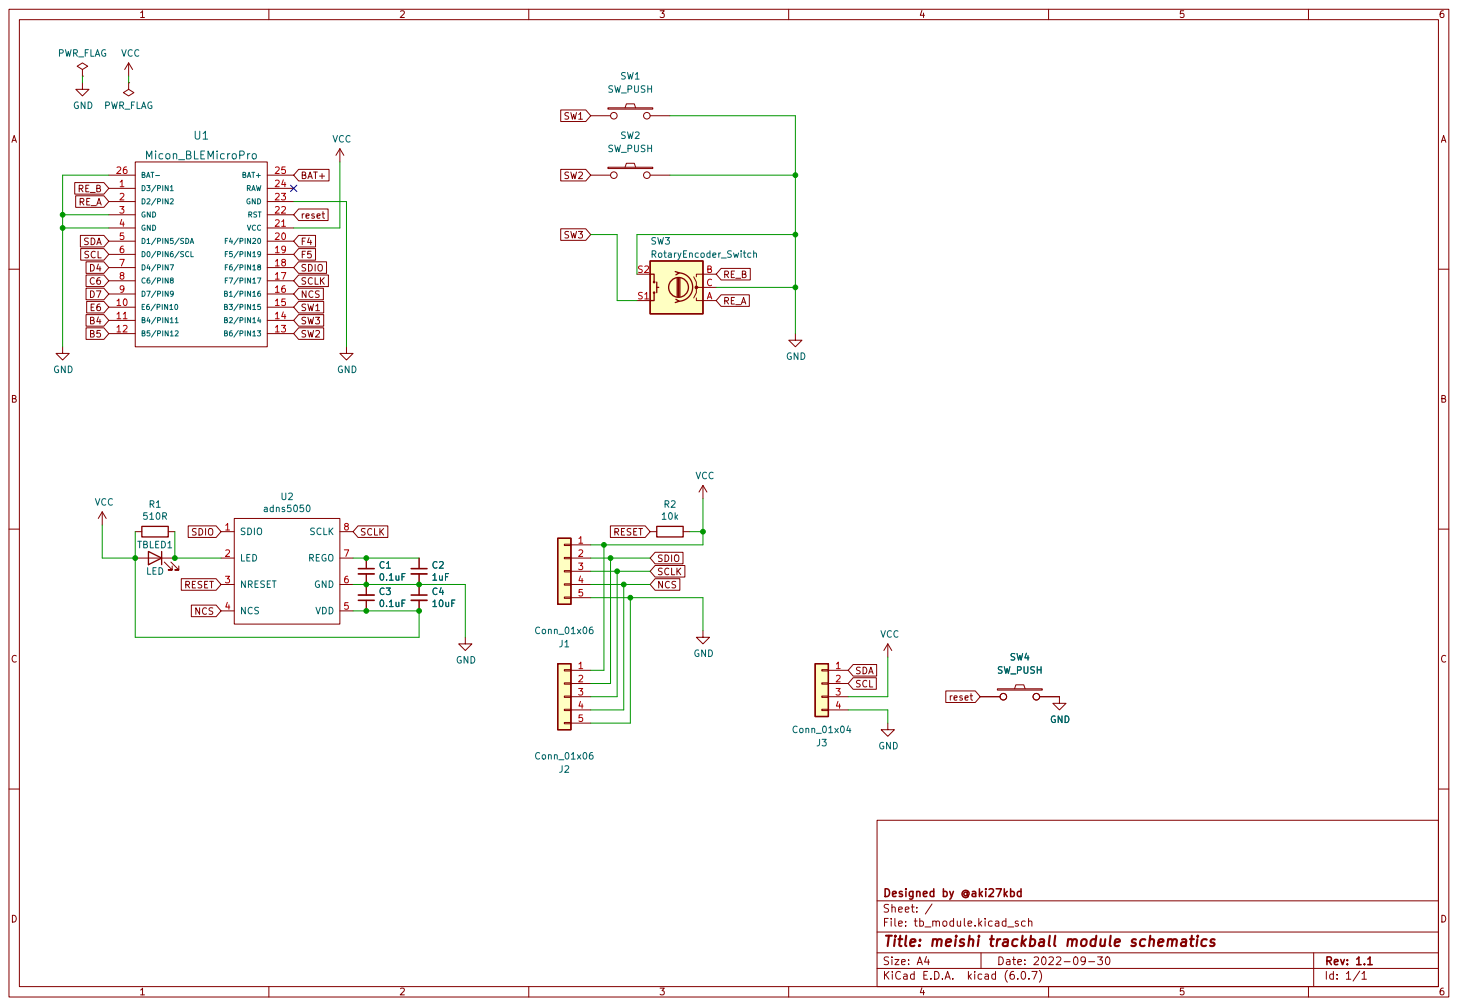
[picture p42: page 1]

File: tb_module.kicad_sch Sheet: / Designed by @aki27kbd C4

Id: 1/1 Title: meishi trackball module schematics

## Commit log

2022-09-21 add BOM
2022-09-21 update BOM
2022-09-30 add dxf data
    [meishi_trackball_module_issue.dxf]
2022-09-30 add schematics
2022-09-30 add acrylic bottom data
    [meishi_trackball_module_issue.dxf]
2022-11-24 add KiCAD symbols and footprints
2022-11-24 revise KiCAD files
